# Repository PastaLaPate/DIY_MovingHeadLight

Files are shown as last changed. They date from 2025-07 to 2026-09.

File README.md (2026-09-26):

# MovingHead DIY






This is a DIY Moving Head project using an ESP32, servos, and RGB LEDs. The project allows you to control the position of the servos and the color of the LEDs via WebSocket.

## Requirements

You will need vscode w/ PlatformIO installed to build and upload the code to your ESP32.

A 3D Printer is recommended to print the parts, but you can also print the parts online.
You can find the 3D models on [Printables](https://www.printables.com/model/1362122-diy-moving-head-led-beam-light) or see last version (might be unstable / broken) on [AutoDesk Fusion HUB](https://a360.co/457yoQi).

Circuit:
ESP32 Or any compatible board (might need to change pin numbers in the code & PlatformIO project)

- 2 Servos (one for the base and one for the top) Recommended: MG90S

> [!NOTE]
> Make sure to use a power supply that can provide enough current for the servos, as they can draw significant current when moving. A separate power supply for the servos is recommended. W/ Common GND

- 1 RGB LED (common anode or common cathode) or 3 individual LEDs (red, green, blue)
- If rgb common anode:
  - 3 IRLZ44N MOSFETs (or similar) for each color channel
- Else:
  - Just skip the MOSFETs in the circuit.
- 1 220 Ohm Resistor for each LED data line
- Between Mosfet drain & LED cathode/anode See `src/SETTINGS.h` for calculating the resistor values, assuming default values + 5V power supply:
  - Red: 150 Ohm
  - Green: 100 Ohm
  - Blue: 100 Ohm
- Breadboard and jumper wires Or PCB

> [!NOTE]
> Here is a pcb made in Easy eda which support up to a 1W RGB Led
> Project : https://oshwlab.com/pastalapate/movinghead_led
> Editor : https://pro.easyeda.com/editor#id=c217a71503914a7fb4df2c4265607413

## Usage

1. Create the file `src/SECRETS.h` following the example in `src/SECRETS.h.example` to define your WiFi credentials.
2. Upload the code to your ESP32 using PlatformIO.
3. Do the circuit

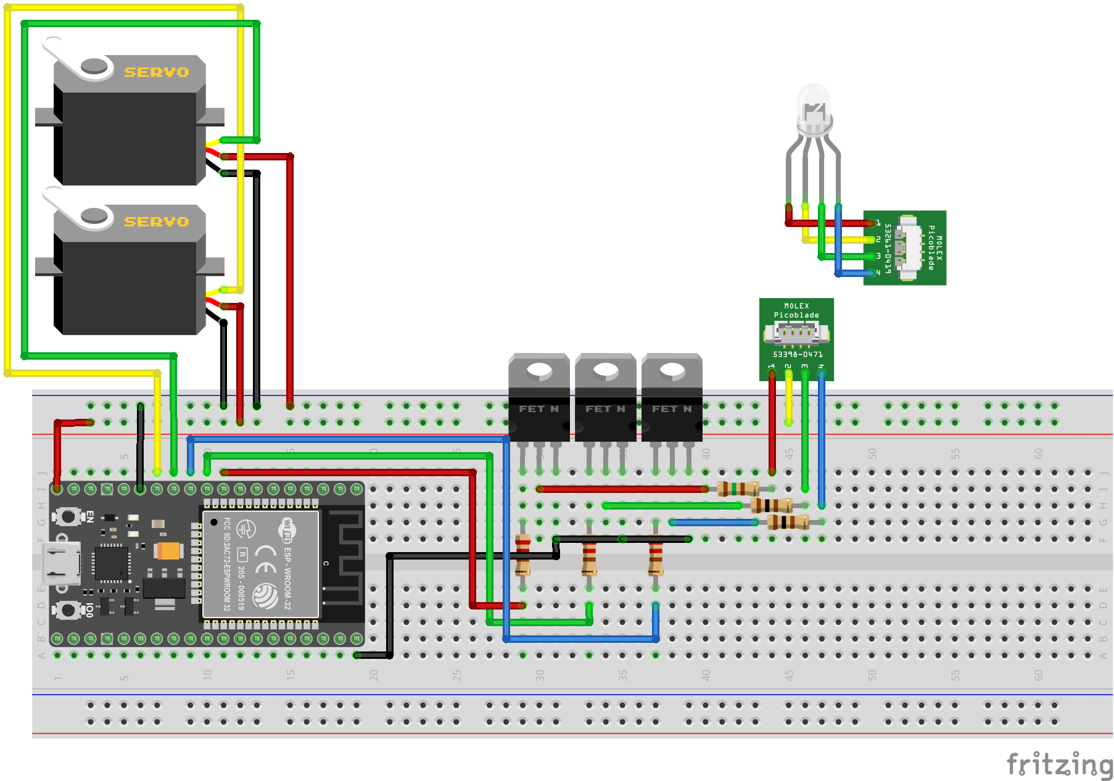
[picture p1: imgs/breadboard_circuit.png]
CircuitDiagram
   

4. Print the 3D models and assemble the moving head.

You can use Light Show Controller to create light shows and control the moving head depending of the current music.

## Custom control

You can now open a WebSocket connection to `ws://<your-esp32-ip>:<port>/ws` to control the servos and LEDs. Port is defined in `src/SETTINGS.h` (default is 81). 3. Use the WebSocket client to send JSON commands to control the servos and LEDs.
JSON Body for controlling servo:

```jsonc
{
  "servo": "top", // "top" or "base"
  "angle": 90 // angle in degrees
}
```

JSON Body for controlling LED color:

```jsonc
{
  "led": {
    "r": 255, // red value (0-255)
    "g": 0, // green value (0-255)
    "b": 0 // blue value (0-255)
  }
}
```

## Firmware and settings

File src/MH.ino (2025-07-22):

#include <SECRETS.h>
#include <SETTINGS.h>

#include <WiFi.h>
#include <ESPAsyncWebServer.h>
#include <ArduinoJson.h>
#include <Servo.h>

// ***** Servo *****
Servo servo;

// ***** LED PWM Channel Configuration *****
const int redChannel    = 0;
const int greenChannel  = 1;
const int blueChannel   = 2;
const int pwmFreq       = 2500;
const int pwmResolution = 8;

// WebSocket server on port 81
AsyncWebServer server(PORT);
AsyncWebSocket ws("/ws");

// Function to smoothly move a servo (adjust speed as needed)
void moveServo(int pin, int angle) {
  servo.write(pin, angle, 2000, 0);
}

// Set the color of the LED
void setColor(int redValue, int greenValue, int blueValue) {
  ledcWrite(redChannel, redValue);
  ledcWrite(greenChannel, greenValue);
  ledcWrite(blueChannel, blueValue);
}

// Handle incoming WebSocket messages
void handleWebSocketMessage(void *arg, uint8_t *data, size_t len) {
  DynamicJsonDocument doc(256);
  // Parse the JSON payload from the WebSocket message
  DeserializationError error = deserializeJson(doc, data, len);
  if (error) {
    Serial.println("Invalid JSON received");
    return;
  }

  // Handle servo commands
  if (doc.containsKey("servo") && doc.containsKey("angle")) {
    int angle = doc["angle"];
    const char* servoName = doc["servo"];
    if (strcmp(servoName, "top") == 0) {
      Serial.printf("Moving top servo to %d°\n", angle);
      moveServo(TOP_SERVO_PIN, angle);
    } else if (strcmp(servoName, "base") == 0) {
      Serial.printf("Moving base servo to %d°\n", angle);
      moveServo(BASE_SERVO_PIN, angle);
    }
  }

  // Handle LED color command
  if (doc.containsKey("led")) {
    int r = doc["led"]["r"];
    int g = doc["led"]["g"];
    int b = doc["led"]["b"];
    Serial.printf("Setting LED color to R:%d, G:%d, B:%d\n", r, g, b);
    setColor(r, g, b);
  }
}

// WebSocket event handler
void onWebSocketEvent(AsyncWebSocket *server, AsyncWebSocketClient *client, AwsEventType type, void *arg, uint8_t *data, size_t len) {
  String msg; // Declare outside switch to avoid bypassing initialization
  switch (type) {
    case WS_EVT_CONNECT:
      Serial.printf("WebSocket client #%u connected from %s\n", client->id(), client->remoteIP().toString().c_str());
      msg = "{\"message\":\"Connected successfully\",\"clientId\":" + String(client->id()) + "}";
      client->text(msg);
      break;
    case WS_EVT_DISCONNECT:
      Serial.printf("WebSocket client #%u disconnected\n", client->id());
      break;
    case WS_EVT_DATA:
      handleWebSocketMessage(arg, data, len);
      break;
    case WS_EVT_PONG:
    case WS_EVT_ERROR:
      break;
  }
}

// ***** Setup *****
void setup() {
  Serial.begin(115200);
  delay(1000);

  // Connect to WiFi
  Serial.printf("Connecting to %s\n", WIFI_SSID);
  WiFi.begin(WIFI_SSID, WIFI_PSWD);
  while (WiFi.status() != WL_CONNECTED) {
    delay(500);
    Serial.print(".");
  }
  Serial.println();
  Serial.print("Connected! IP address: ");
  Serial.println(WiFi.localIP());

  // Initialize LED PWM channels
  ledcSetup(redChannel, pwmFreq, pwmResolution);
  ledcSetup(greenChannel, pwmFreq, pwmResolution);
  ledcSetup(blueChannel, pwmFreq, pwmResolution);
  ledcAttachPin(RED_PIN, redChannel);
  ledcAttachPin(GREEN_PIN, greenChannel);
  ledcAttachPin(BLUE_PIN, blueChannel);

  // Attach servos
  servo.attach(TOP_SERVO_PIN, 4);
  servo.attach(BASE_SERVO_PIN, 5);

  // Start WebSocket server
  ws.onEvent(onWebSocketEvent);
  server.addHandler(&ws);
  server.begin();
  Serial.printf("WebSocket server started on port %d \r\n", PORT);
}

// ***** Main Loop *****
void loop() {
  // Clean up disconnected clients
  ws.cleanupClients();
}

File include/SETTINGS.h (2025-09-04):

#define PORT 81

// SERVOS
#define TOP_SERVO_PIN 12
#define BASE_SERVO_PIN 14

// LED Pins
#define RED_PIN 25
#define GREEN_PIN 26
#define BLUE_PIN 27

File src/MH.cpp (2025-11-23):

#include <Arduino.h>

#include <SECRETS.h>
#include <SETTINGS.h>

#include <WiFi.h>
#include <ArduinoJson.h>

#include <ServoUtils.h>
#include <LedUtils.h>
#include <ServerUtils.h>

// TODO: Make led blue blinking while connecting, green while starting etc...

// ***** Setup *****
void setup()
{
  Serial.begin(115200);
  delay(1000);
  Serial.println("**************************");
  Serial.println("    Moving Head Light");
  Serial.println("**************************");
  Serial.println();
  Serial.println("Setuping leds & servos...");
  setupLEDPWM(RED_PIN, GREEN_PIN, BLUE_PIN);
  initServo();
  flicker(255, 0, 0, 500);
  // Connect to WiFi
  Serial.printf("Connecting to %s\n", WIFI_SSID);
  WiFi.begin(WIFI_SSID, WIFI_PSWD);
  while (WiFi.status() != WL_CONNECTED)
  {
    fadeToColor(0, 0, 0, 0, 0, 255, 500, EASE_IN_CUBIC);
    Serial.print(".");
    fadeToColor(0, 0, 255, 0, 0, 0, 500, EASE_IN_CUBIC);
  }
  setColor(255, 255, 255);
  Serial.println();
  Serial.print("Connected! Local Wifi IP address: ");
  Serial.println(WiFi.localIP());
  Serial.print("RSSI: ");
  Serial.println(WiFi.RSSI());
  Serial.println("Setuping AsyncWebServer & WebSocket...");
  setupServer();
  // Start WebSocket server
  Serial.printf("WebSocket server started on port %d \r\n", PORT);
  Serial.println("Operational!");
  flicker(0, 255, 0, 1000);
}

// ***** Main Loop *****
void loop()
{
  loopServer();
}

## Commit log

2025-07-22 Fixed dependencies + added separated settings
    [MH.ino, SETTINGS.h]
2025-07-22 Added fritzing project
    [movinghead.fzz]
2025-07-22 Added images
    [movinghead.fzz]
2025-07-22 Added shields & changed printables link
2025-07-22 Changed fritzing to add resistor between mosfet & rgb led & added resistance calculations in src/SETTINGS.h
    [movinghead.fzz]
2025-07-23 Fixed example secrets file & converted to cpp
    [MH.cpp]
2025-07-23 Splitted MH.cpp file to LedUtils + Better simulation + Fading light
2025-11-23 Fixes & optimizations + fixed sim
    [LedUtils.cpp, MH.cpp, ServerUtils.cpp]
2025-12-08 Added pcb
2026-10-23 fix: smaller screw holes, smaller height overall to let screws pass over
2026-10-23 feat: finished arm 2 of fork
2026-10-23 fix: more place for the servo
2026-10-23 feat: new mount system for servo on fork + chamfer on bearing extrusion
2026-10-24 fix: impossible to led to light up again
2026-10-25 added PCB files
2026-10-28 feat: servo spreadsheet in freecad, remade gitignores

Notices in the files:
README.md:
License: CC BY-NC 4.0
